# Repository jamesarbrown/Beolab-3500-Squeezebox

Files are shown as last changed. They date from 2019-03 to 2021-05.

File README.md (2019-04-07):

# Beolab-3500-Squeezebox

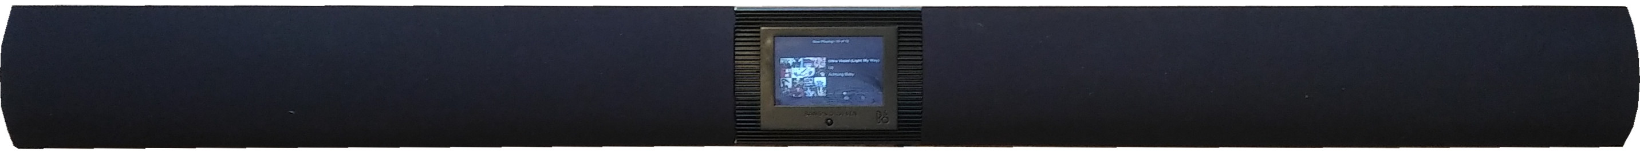
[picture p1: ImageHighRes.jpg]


This project is to convert and Bang and Olufsen Beolab 3500 into a Logitech Media Server / Slimdevices Squeezebox using Raspberry Pi and PiCorePlayer.

My first Squeezebox1 I bought from the US direct, long long before it was into the UK and since the range has been obsoleted by Logitech I wanted something a bit more than a streamer alone. There is a lot of B&O stuff in our family and it was a natural way to go, and most elegant equipment that has like all electronic stuff is soon out of date.

The project has a requirement for 3d printed parts and homemade PCBs

In no way is this project affiliated or representative of Bang and Olufsen, Logitech or Slimdevices. I have utilised the logos in my fascia designs, but if they need removing as companies sometimes do, I can do that, but don't feel this harms your brand identities. 

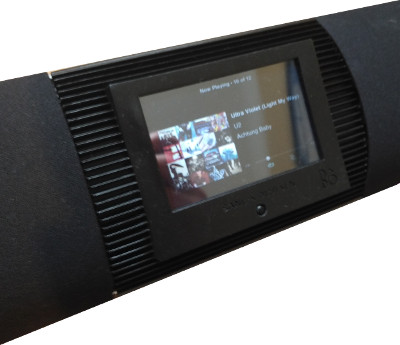
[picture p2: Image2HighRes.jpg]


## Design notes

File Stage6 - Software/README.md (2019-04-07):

## Installing and Setting Up

At the time of writing this is based on PiCorePlayer 4.1. I wont go into high details here just overview of tasks.

### Tasks

Once into PiCorePlayer web front end perform the following tasks

* Resize FS to whole SD Card
* Enable FFMPEG Libraries
* Setup HDMI detailed below
* Install jivelite via pCP web page
* Install Lirc as detailed below (this is important to do so we can set the jivelite resolution!)
* Set Skin to 640 x 480, this must match the hdmi_cvt settings (so the touch resolution matches the skin)
* Backup your settings on the pcp webpage

### Extensions to Enable
* nano

### Setup HDMI (KeDEI HDMI Screen 3.5")

In Rasberry config.txt File, (to edit ssh to PiCorePlayer, type m1, c1 and then ls to get to the file) edit as follows

At the end of the file add the HDMI info between the custom lines
```
#Custom Configuration Area, for config settings that are not managed by pCP.
#pCP will retain these settings during insitu-update
#---Begin-Custom-(Do not alter Begin or End Tags)-----
#For the display
hdmi_force_hotplug=1
hdmi_group=2
hdmi_mode=1
hdmi_mode=87
hdmi_cvt 640 480 60 6 0 0 0
hdmi_drive=2
display_rotate=2

#For the touchscreen
dtoverlay=ads7846,cs=0,penirq=25,speed=10000,penirq_pull=2,keep_vref_on=1,xohms=150
#---End-Custom----------------------------------------
```

### Install LIRC

Install lirc via the pCP web page
Once rebooted go back into the Lirc page and set the GPIO to 18 (if using the connections in this project)

### Setup the touchscreen

Run the commands and follow screen. Note that you need to disable jivelite autostart if you skipped ahead and have installed that. Once done you can reenable the autostart.

___ It must match the screen resolution set in config.txt and the skin resolution ___

___ It must be run as root... running as sudo does not change root settings which pcp runs on ___

```
root@piCorePlayer:/mnt/mmcblk0p1$ cat /proc/bus/input/devices
I: Bus=0000 Vendor=0000 Product=0000 Version=0000
N: Name="ADS7846 Touchscreen"
P: Phys=spi0.0/input0
S: Sysfs=/devices/platform/soc/3f204000.spi/spi_master/spi0/spi0.0/input/input0
U: Uniq=
H: Handlers=mouse0 event0
B: PROP=0
B: EV=b
B: KEY=400 0 0 0 0 0 0 0 0 0 0
B: ABS=1000003

root@piCorePlayer:~$ TSLIB_TSDEVICE=/dev/input/event0 /usr/local/bin/ts_calibrate
xres = 640, yres = 480
Took 1 samples...
Top left : X =  358 Y = 3832
Took 4 samples...
Top right : X =  215 Y =  201
Took 7 samples...
Bot right : X = 3652 Y =  228
Took 6 samples...
Bot left : X = 3659 Y = 3939
Took 3 samples...
Center : X = 2048 Y = 2000
658.083069 0.003269 -0.168910
-25.536713 0.136478 -0.002727
Calibration constants: 43128132 214 -11069 -1673574 8944 -178 65536
```
Can then be tested via
```
root@piCorePlayer:~$ TSLIB_TSDEVICE=/dev/input/event0 /usr/local/bin/ts_test
```

And don't forget
```
filetool.sh -b
```

### Edit pcpstartup
/home/tc/www/cgi-bin/pcp_startup.sh
Comment out the FT5406 and force the event no
```
eventno=$( cat /proc/bus/input/devices | awk '/FT5406 memory based driver/{....
```
to
```
eventno=$( cat /proc/bus/input/devices | awk '/ADS7846 Touchscreen/{....
```
And then don't forget to filetool.sh -b

This sets the following environment flags

```
export JIVE_NOCURSOR=1
export TSLIB_TSDEVICE=/dev/input/$eventno
export SDL_MOUSEDRV=TSLIB
export SDL_MOUSEDEV=$TSLIB_TSDEVICE

```
### Scripts for PON PLIM, PMUTE etc
In this folder is a file called beo3500.sh.

Please copy this into /home/tc and then in user commands in the pCP webinterface add

```
sleep 5; /home/tc/beo3500.sh > /dev/null
```

The script will auto power on and off the amplifiers based on the player status.

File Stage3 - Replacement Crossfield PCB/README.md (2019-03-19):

## Stage 3 - Replacement Crossfield and Ribbon Cables

### Ribbon Cable Replacements

| Function | New Length | Ways | Socket on Beolab | RS PN Plugs |
| --- |:---:| :---:| :---: | ---: |
| Right Hand Side Amp | 380mm | 8 | P2 | 680-5148 |
| Left Hand Side Amp  | 520mm | 8 | P2 | 680-5148 |
| Right Hand Side Amp | 370mm | 12 | P18 | 680-4933 |
| TX "Left" | 520mm | 4 | P21 | 341-7349 |

Note 10 way ribbon P17 to P5 is removed and not replaced. On ribbon cable bought a length of 14 way and cut down for other sections

In later stages the right hand side and left hand amps will be swapped around to create space for the crossfield PCB

## Crossfield PCB Folders

I made the PCB utilising laser printer thermal transfer method. 

In the following folders please finds

### PDFs

Crossfield PCB.pdf - The PCB to Print

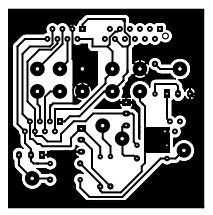
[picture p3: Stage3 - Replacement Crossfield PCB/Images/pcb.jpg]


Crossfield Schematic.pdf - The Schematic of the above PCB

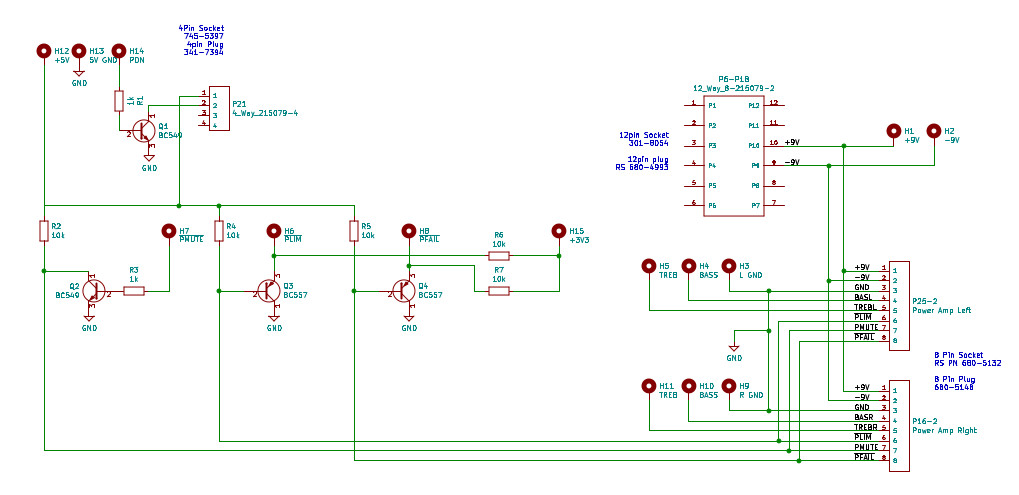
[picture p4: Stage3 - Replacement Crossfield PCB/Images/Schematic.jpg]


### Crossfield PCB Replacement (KiCAD Project)
The original KiCAD Design files, including the TE connectivity plugs and so on

#### Notes 
I had difficulty in nailing down the PFAIL and PLIM functions, so copied the way they originally were immplemented into the B&O microcomputer. Then used a BC549 to separate the circuit from the Raspberry. My suspicion was I could pull down the 3v3 directly, but went for this way to achieve some security.

### 3d from Kicad of PCB

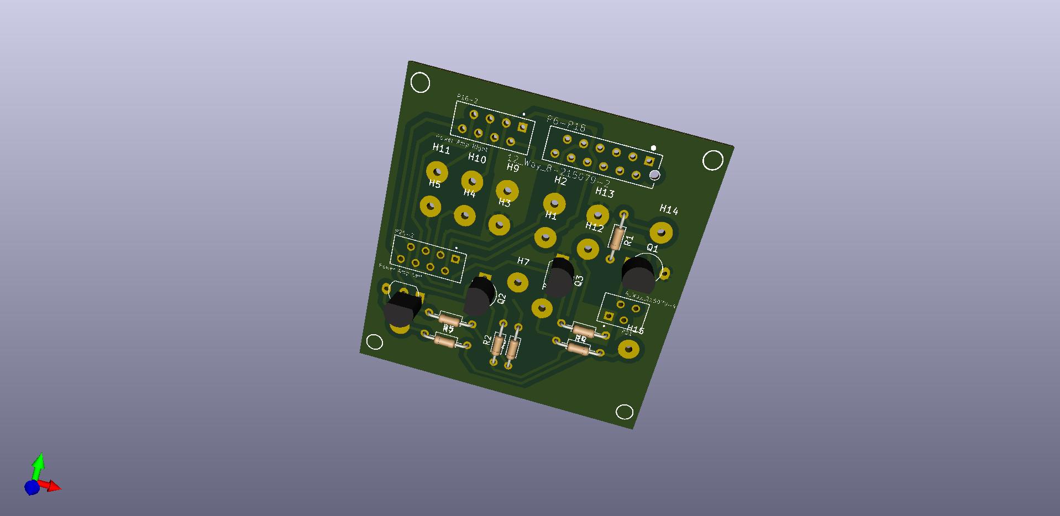
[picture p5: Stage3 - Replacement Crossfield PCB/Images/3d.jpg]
3d


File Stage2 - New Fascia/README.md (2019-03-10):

## Stage 2 - New Fascia

The fascia holds the Raspberry pi, the screen, the KM Tech cross overs.

### 3d Renders

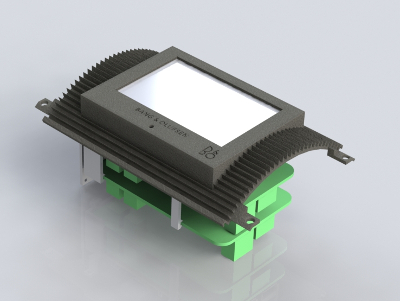
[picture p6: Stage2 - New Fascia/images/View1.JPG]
Render1


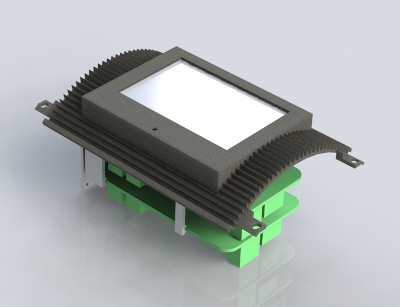
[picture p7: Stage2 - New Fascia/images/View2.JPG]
Render2


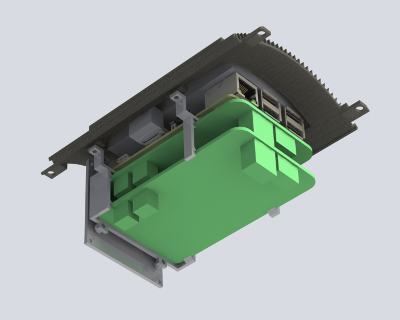
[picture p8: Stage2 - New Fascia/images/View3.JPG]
Render3


### IR Receiver

The IR receiver I bonded to the back of the fascia. This one is a TSOP4838

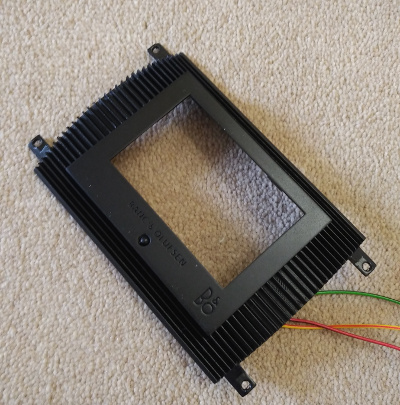
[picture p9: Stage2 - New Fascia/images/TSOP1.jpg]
TSOP1


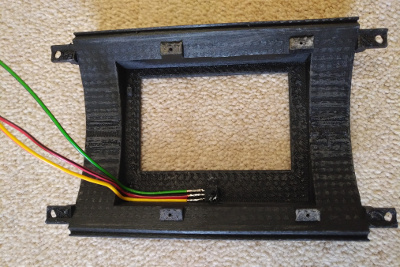
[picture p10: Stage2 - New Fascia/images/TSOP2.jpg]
TSOP2


#### Misc Notes

I found the Kedei screen was at a 1mm angle, so there is a 1mm thick printable wasaher as a spacer included in this project

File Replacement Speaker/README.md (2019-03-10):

## Replacing the B&O Original Speakers with Alternative
This section was implmented as during my investigations one of my speakers was damaged and the coil scratching.

The bracket detailed in here is to accept a Visatron FRS8 speaker 8Ohm 30watt. The B&O speaker is 3.25" which is very odd and forms part of the plastics. This speaker is 3".

The original Solidworks file is here should you want to utilise an alternative speaker

### Original Speaker with Foam Removed, before I realised it was far more damaged
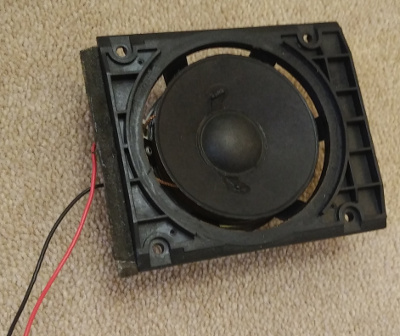
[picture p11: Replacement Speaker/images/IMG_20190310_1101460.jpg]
Speaker Original


### Replacement Speaker and Bracket
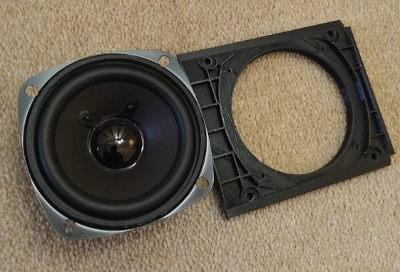
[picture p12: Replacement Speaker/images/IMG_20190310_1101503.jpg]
Speaker New 1

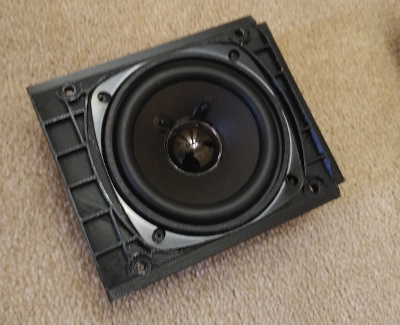
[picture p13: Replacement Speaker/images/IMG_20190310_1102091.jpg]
Speaker New 2


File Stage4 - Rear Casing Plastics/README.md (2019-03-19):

## Rear Casing Plastics

Due to removal of the aluminium diecast parts to make space for this project, I needed to make a new rear casing.

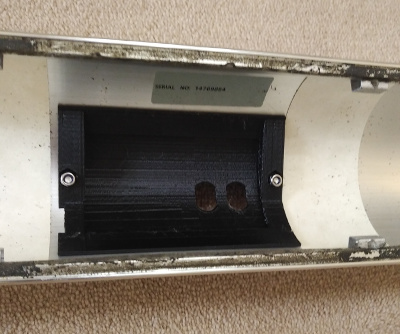
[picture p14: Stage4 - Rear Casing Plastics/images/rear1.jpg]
rear1


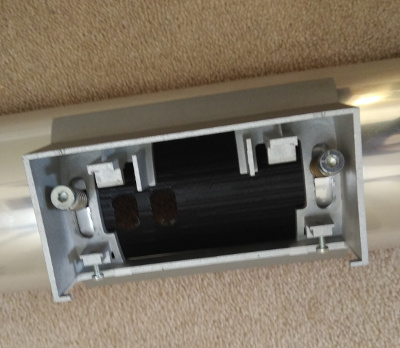
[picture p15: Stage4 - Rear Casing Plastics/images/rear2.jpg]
rear2


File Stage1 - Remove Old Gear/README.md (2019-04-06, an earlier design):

## Stage 1 - Removed the old parts

First I removed the old parts including
* Micro computer
* Alu Brackets
* Lifted out the amps and removed the ribbons

### Here is a Photo just as I began to attach new ribbons (Detailed in Stage 2)

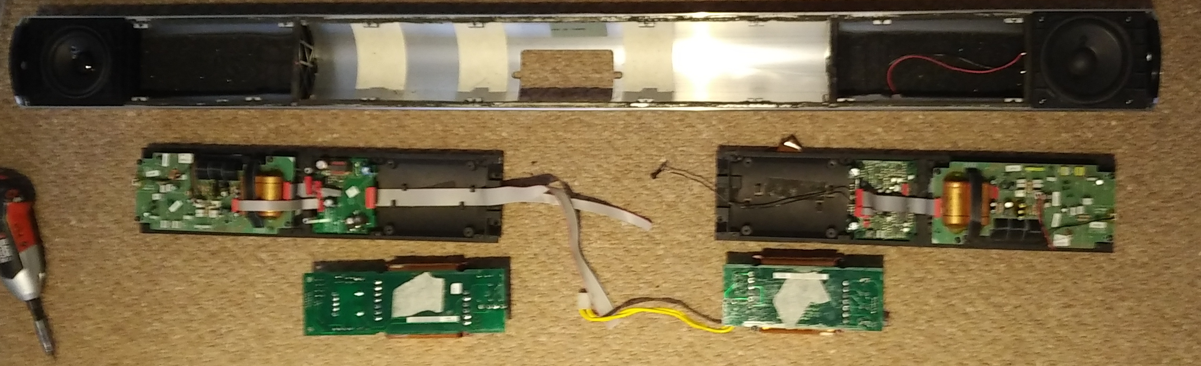
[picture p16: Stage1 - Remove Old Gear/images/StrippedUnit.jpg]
Stripped Down BeoLab3500


_Note the Switchmode PSU was later removed and also the TX modified. See wiring overview. Also the Rh and LH amps will be swapped for space reasons

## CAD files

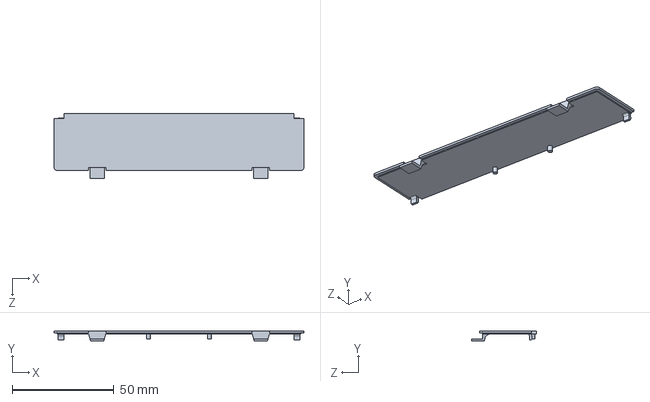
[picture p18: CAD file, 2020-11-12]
3500ReplacementCover/Replacement Cover.SLDPRT
123.0 x 5.00 x 32.0 mm

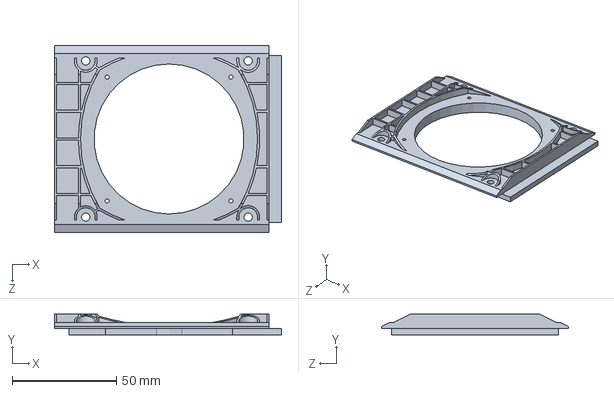
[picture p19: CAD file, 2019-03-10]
Replacement Speaker/Speaker Bracket.SLDPRT
109.0 x 10.0 x 90.0 mm

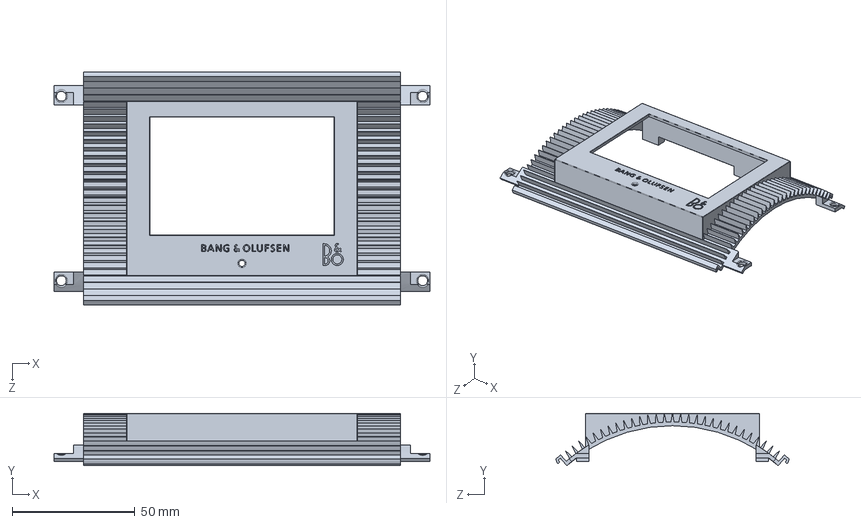
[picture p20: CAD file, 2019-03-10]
Stage2 - New Fascia/Solidworks Files/New Front.SLDPRT
153.0 x 21.3 x 95.0 mm

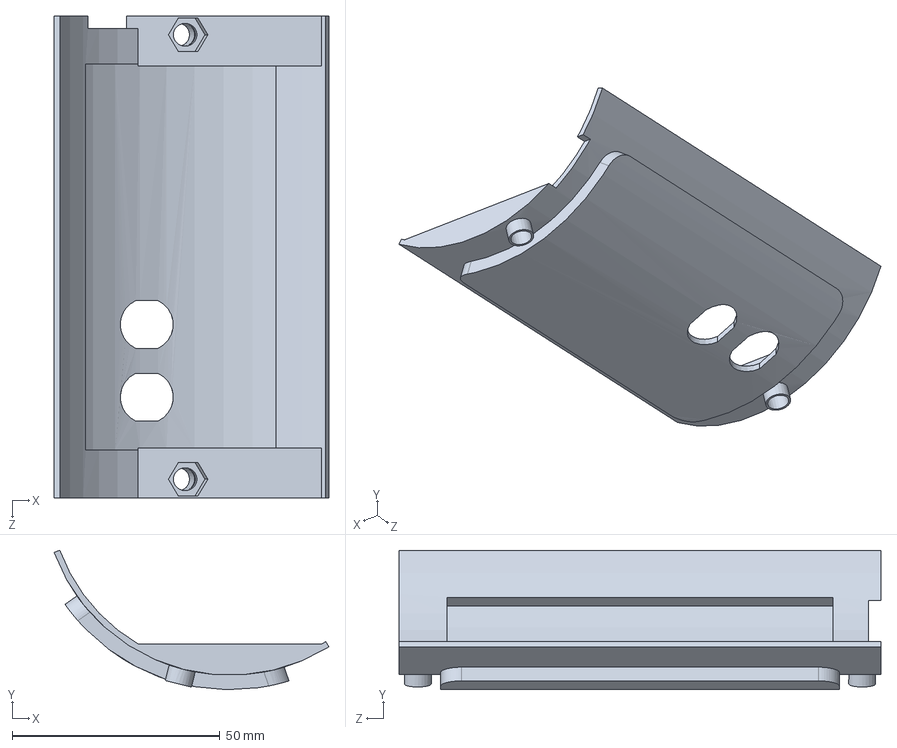
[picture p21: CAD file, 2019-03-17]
Stage4 - Rear Casing Plastics/3d Files/RearCasing.SLDPRT
66.2 x 33.6 x 116.0 mm

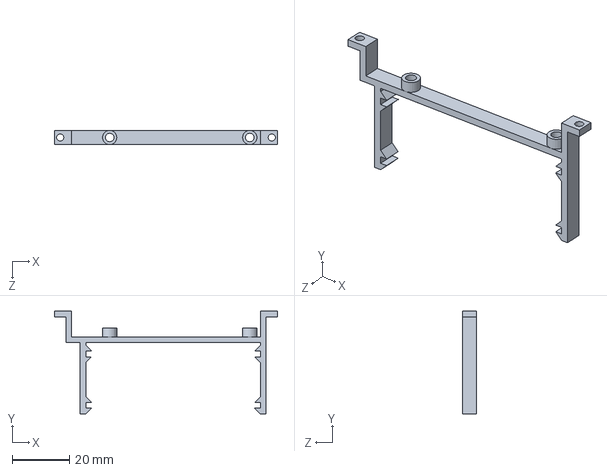
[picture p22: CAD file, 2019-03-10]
Stage2 - New Fascia/Solidworks Files/Bracket Fixing.SLDPRT
78.0 x 36.0 x 5.00 mm

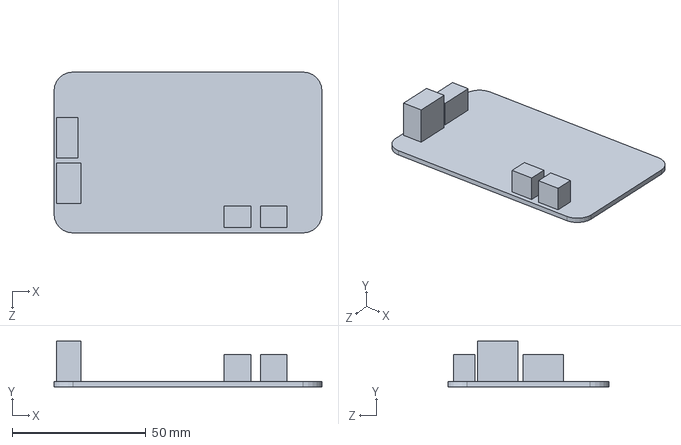
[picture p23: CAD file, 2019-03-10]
Stage2 - New Fascia/Solidworks Files/KMTech Active Filter.SLDPRT
100.0 x 17.0 x 60.0 mm

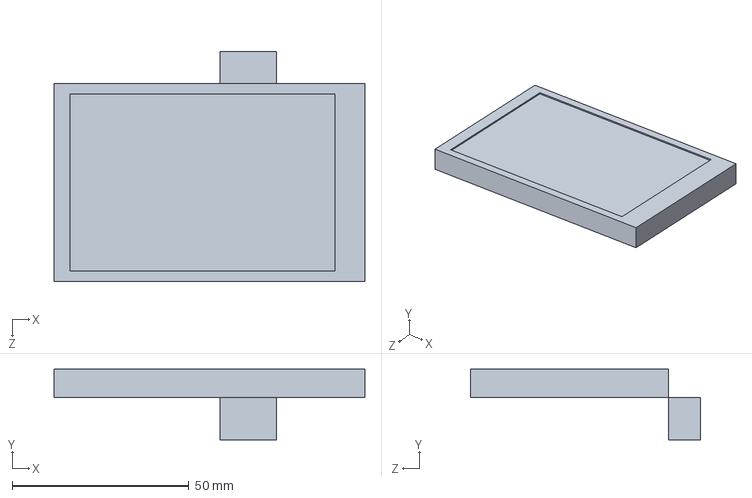
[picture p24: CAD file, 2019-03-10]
Stage2 - New Fascia/Solidworks Files/Kedei Display.SLDPRT
88.0 x 20.0 x 65.0 mm

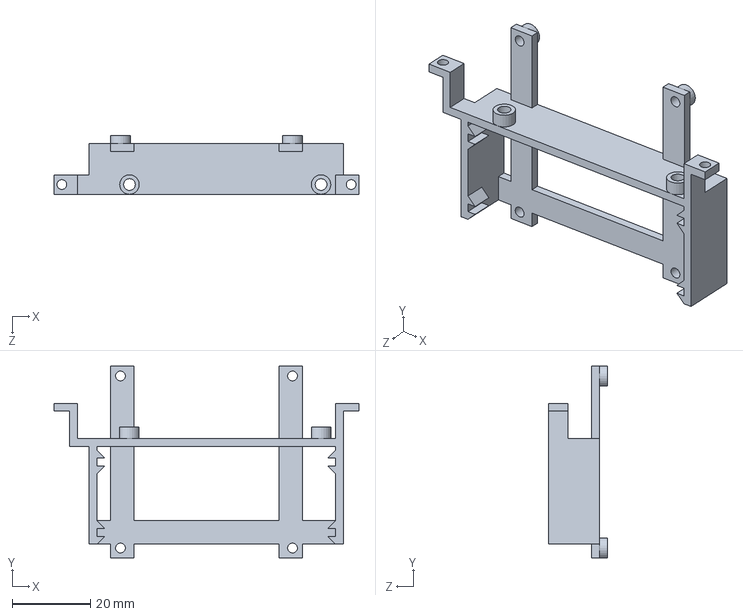
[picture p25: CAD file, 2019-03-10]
Stage2 - New Fascia/Solidworks Files/Bracket Fixing B.SLDPRT
78.0 x 49.0 x 15.0 mm

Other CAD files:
3500ReplacementCover/Replacement Cover.3MF
Replacement Speaker/Speaker Bracket.STL
Stage2 - New Fascia/STL Files/Bracket Fixing B.STL
Stage2 - New Fascia/STL Files/Bracket Fixing.STL
Stage2 - New Fascia/STL Files/New Front.STL
Stage4 - Rear Casing Plastics/3d Files/RearCasing.3MF

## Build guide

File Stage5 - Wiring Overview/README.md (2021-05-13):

## Wiring Overview

### Left Hand Side Amp Prep
The switchmode PSU onboard the Beolab is controlled via a LM3578 Buck convertor. It creates the 5v @ 750mA. Initially it was intended to use this however the Pi turns to be a bit power hungry and official PSU pulls 2A

This is the PSU

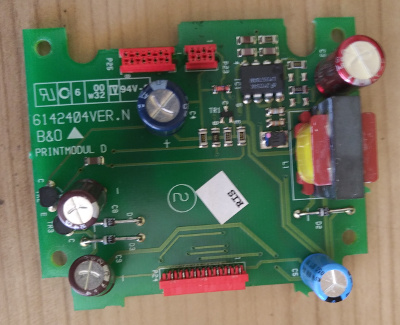
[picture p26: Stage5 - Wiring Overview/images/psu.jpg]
PSU


Then to create a bit more space remove the TX T1 and capacitor C1 from the left hand side TX.

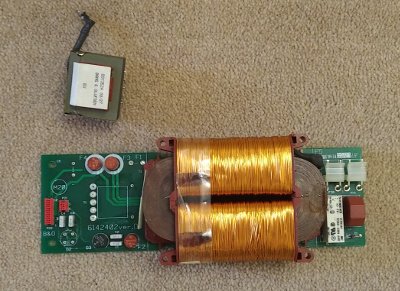
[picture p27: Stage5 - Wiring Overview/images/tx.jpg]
tx


After a second failed attempt with a Samsung PSU, a third failed attempt with a "cheap" 2A and audio noise, finally I bought a Raspberry PSU and but the case in two. Here is the PSU bonded in its final position.

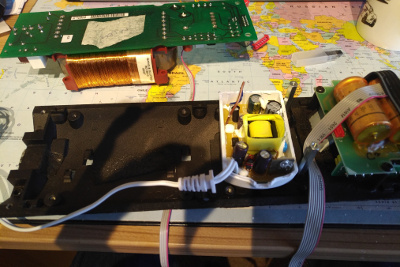
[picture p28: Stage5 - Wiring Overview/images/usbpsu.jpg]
usbpsu


Connect to the B&O pcb where Live and Neutral used to be for the Mini TX

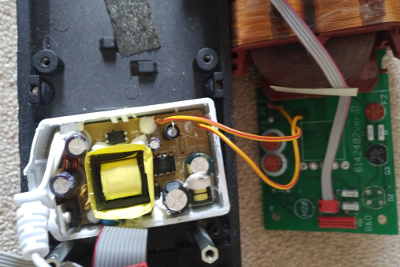
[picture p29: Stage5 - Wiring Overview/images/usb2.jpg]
usb2


I extracted the AC plug pins and soldered a longer flex onto it

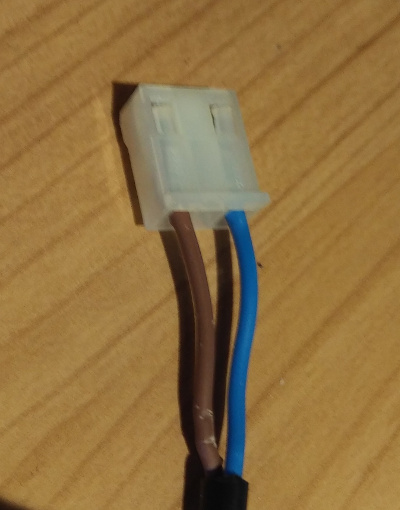
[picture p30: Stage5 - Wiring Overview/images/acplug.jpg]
acplug


Then finally fitted the Left hand system, but in the _RIGHT_ hand side, this is important as the display orientation, the gear around it, means this assembly with is stuck out PCB must go on the right. On the left it will not fit!

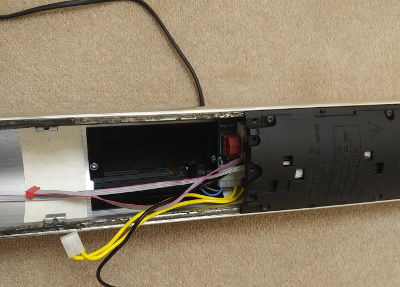
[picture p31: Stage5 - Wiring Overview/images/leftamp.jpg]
leftamp


Note the ferrite core I attached to the DC cable RS PN 123-2479

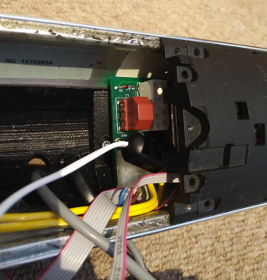
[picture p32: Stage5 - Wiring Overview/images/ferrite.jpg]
ferrite


### Main Wiring Diagram

The main wiring diagram is included in this folder in ODG and PDF format

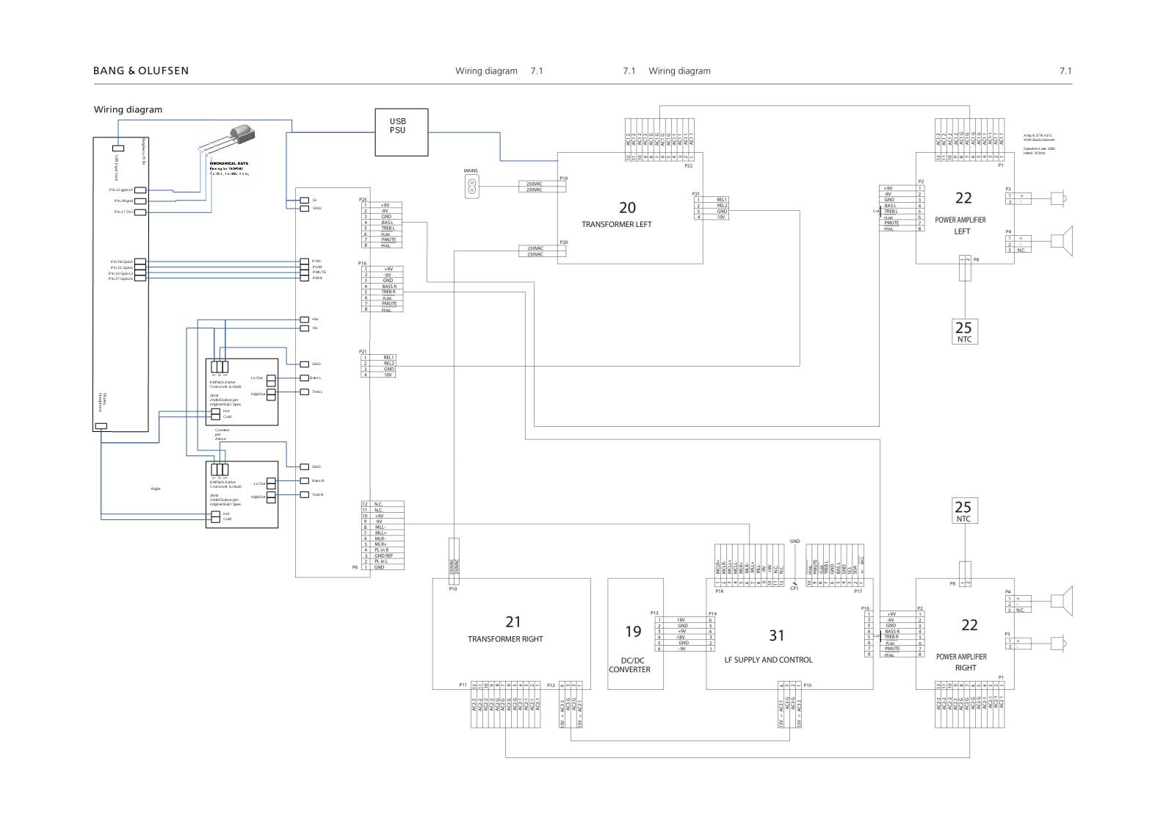
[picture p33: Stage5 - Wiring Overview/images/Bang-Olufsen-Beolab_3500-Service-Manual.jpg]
Wiring


### KM Tech Crossovers

In line with the B&O service manual the crossover needs to be 3kHz and on this project KM Tech units were utilisied. It would have been more ideal to have everything on one board and tighter spacing, so maybe a future implementation.

[Link to Buying on Ebay](https://www.ebay.co.uk/itm/122126121492?hash=item1c6f48ba14:g:sCAAAOSw-kdX07iY)

### Other Notes

After a failed attempt with a bad connection and bad audio from the primary 3.5mm Audio jack, i decided to solder the audio leads directly onto the audio jack for the Kedei display. On the body there is sufficient exposed metal to solder too without having to demount or worry about PCB work.

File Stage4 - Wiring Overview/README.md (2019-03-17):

##Wiring Overview

###Removal of B&O Switchmode PSU

The switchmode PSU onboard the Beolab is controlled via a LM3578 Buck convertor. It creates the 5v @ 750mA. Initially it was intended to use this however on startup the voltage was found to collapse

This is the PSU
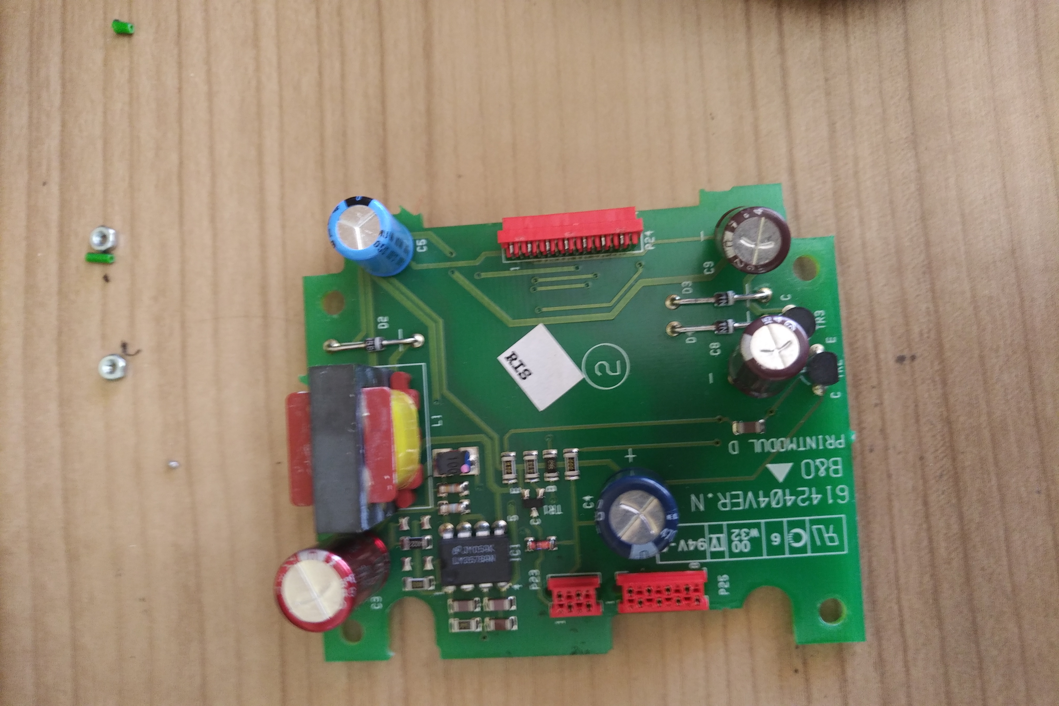
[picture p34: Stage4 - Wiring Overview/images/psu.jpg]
PSU


The Kedei and Raspberry use about 750mA Combined, there was a view to shorting the R4+R5 resistors out on the switchmode, but in diagnosis I damaged the LM3578. So decided to dispose and replace with a typical USB PSU designed for the job

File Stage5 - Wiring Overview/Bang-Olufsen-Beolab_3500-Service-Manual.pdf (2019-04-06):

# USB PSU

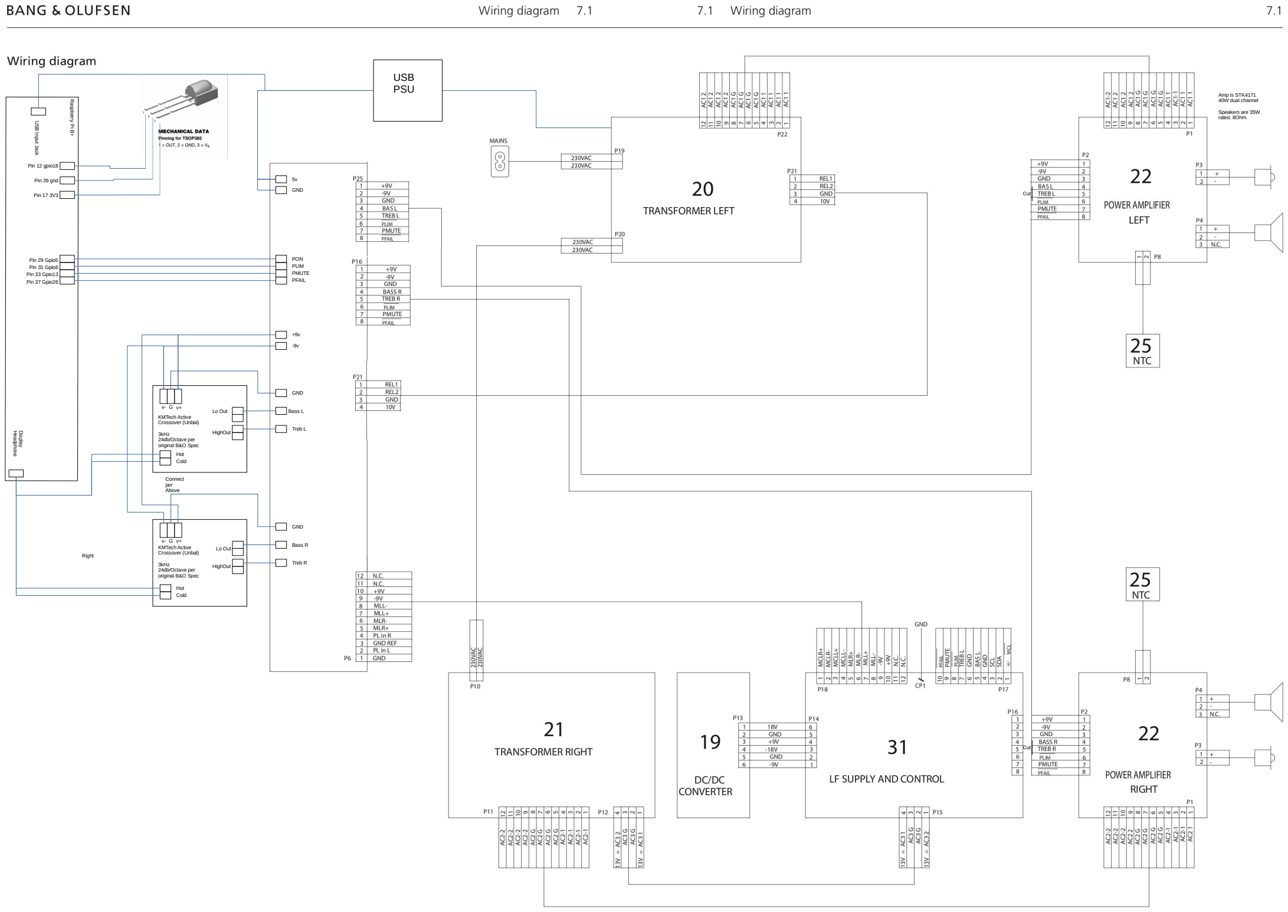
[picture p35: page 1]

Cut

HighOut

Cut

v-

G v+
KMTech Active
Crossover (Unbal)

3kHz
24db/Octave per
original B&O Spec

Amp is STK4171
40W dual channel

Speakers are 35W
rated. 8Ohm.

Raspberry Pi B+

Display

Headphone

Cold

Hot

USB Input Jack

HighOut

Lo Out

v-

G v+
KMTech Active
Crossover (Unbal)

3kHz
24db/Octave per
original B&O Spec

Cold

Hot

Right

Connect
per
Above

Pin 29 Gpio5

Pin 17 3V3

Pin 39 gnd

Pin 12 gpio18

Lo Out

Bass R

Treb R

Bass L

Treb L

GND

GND

+9v

-9v

PON
Pin 31 Gpio6 | PLIM
Pin 33 Gpio13 | PMUTE
Pin 37 Gpio26 | PFAIL

5v

GND

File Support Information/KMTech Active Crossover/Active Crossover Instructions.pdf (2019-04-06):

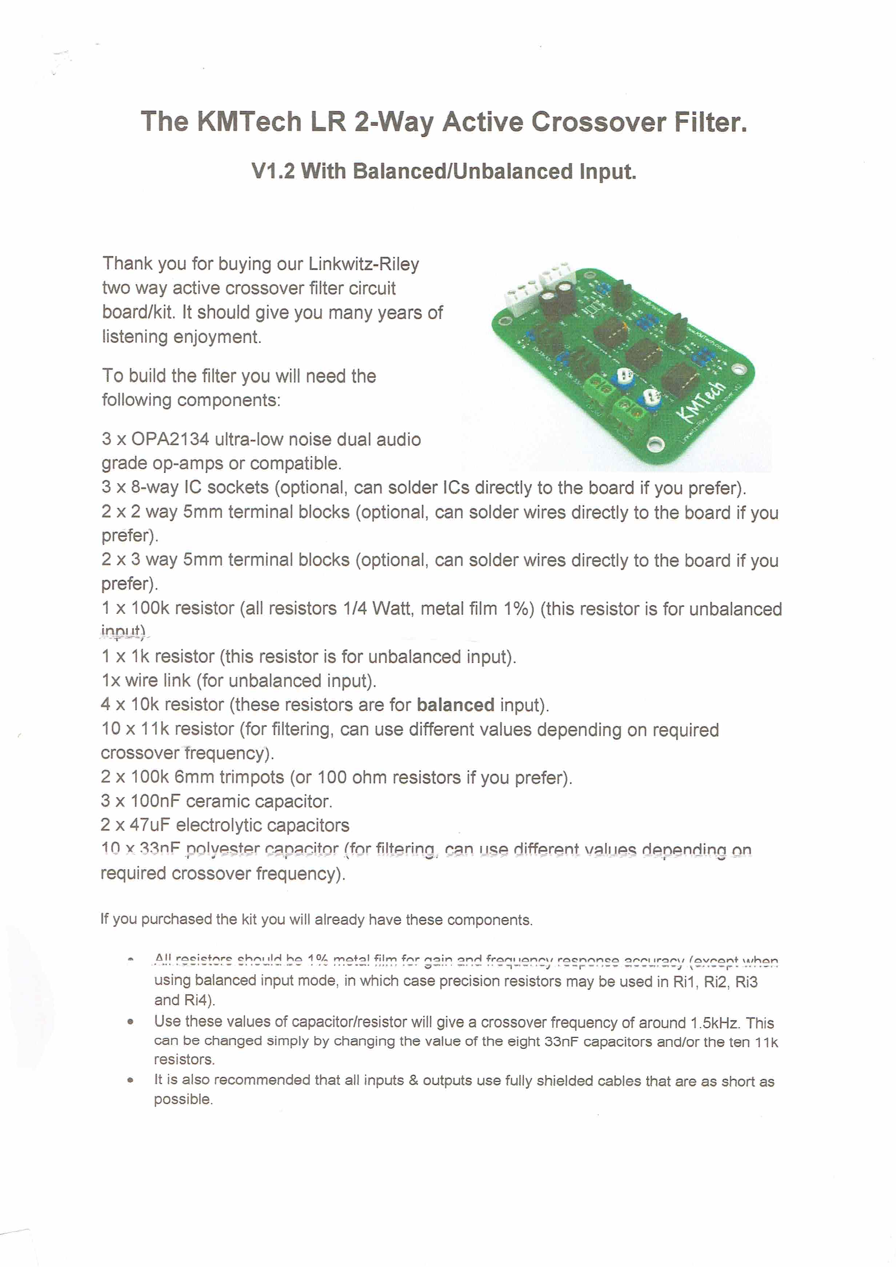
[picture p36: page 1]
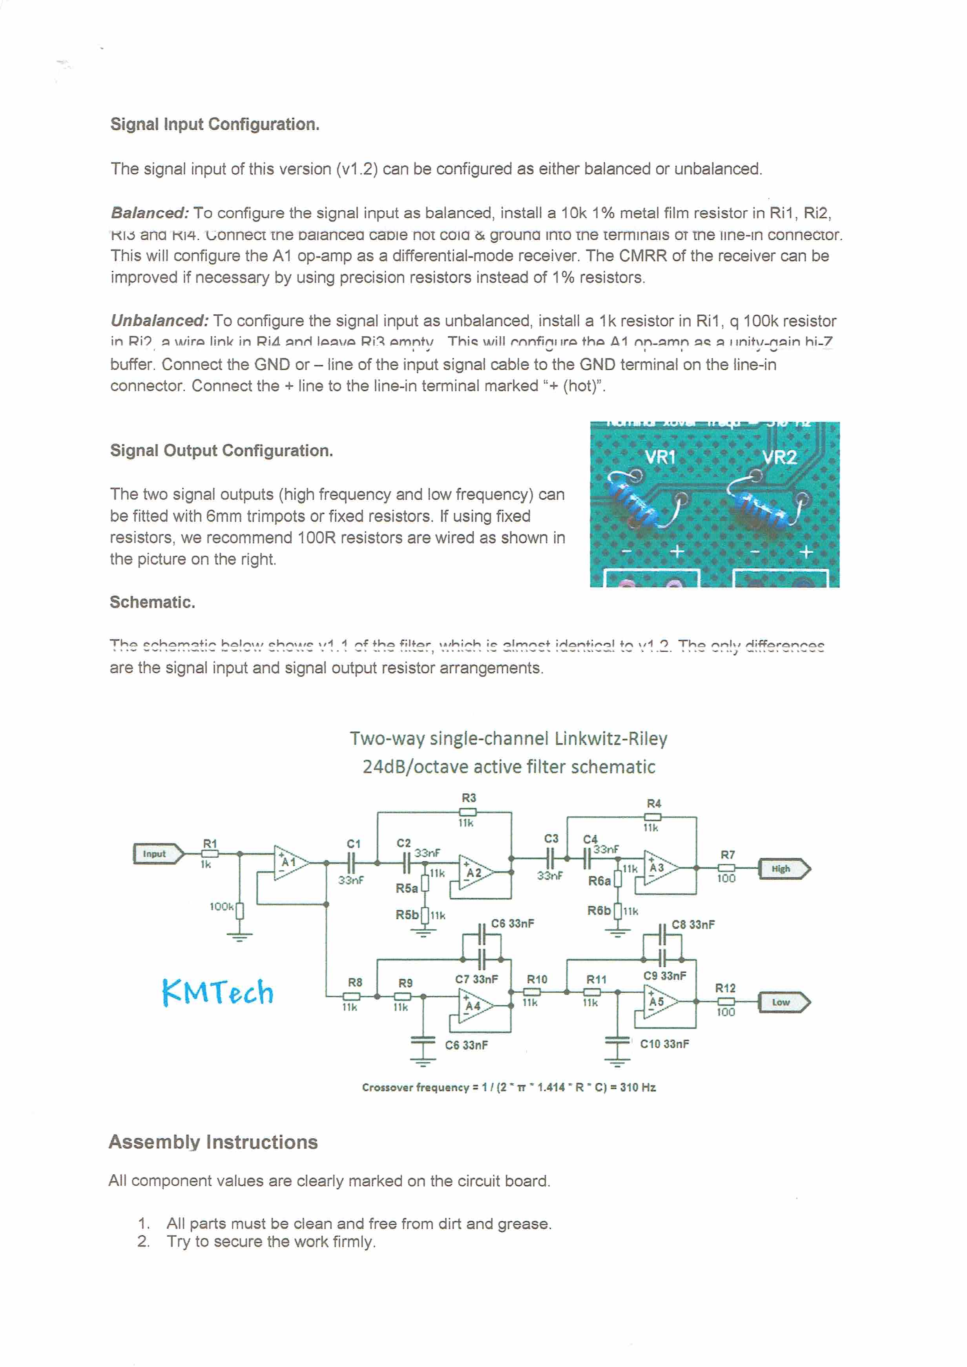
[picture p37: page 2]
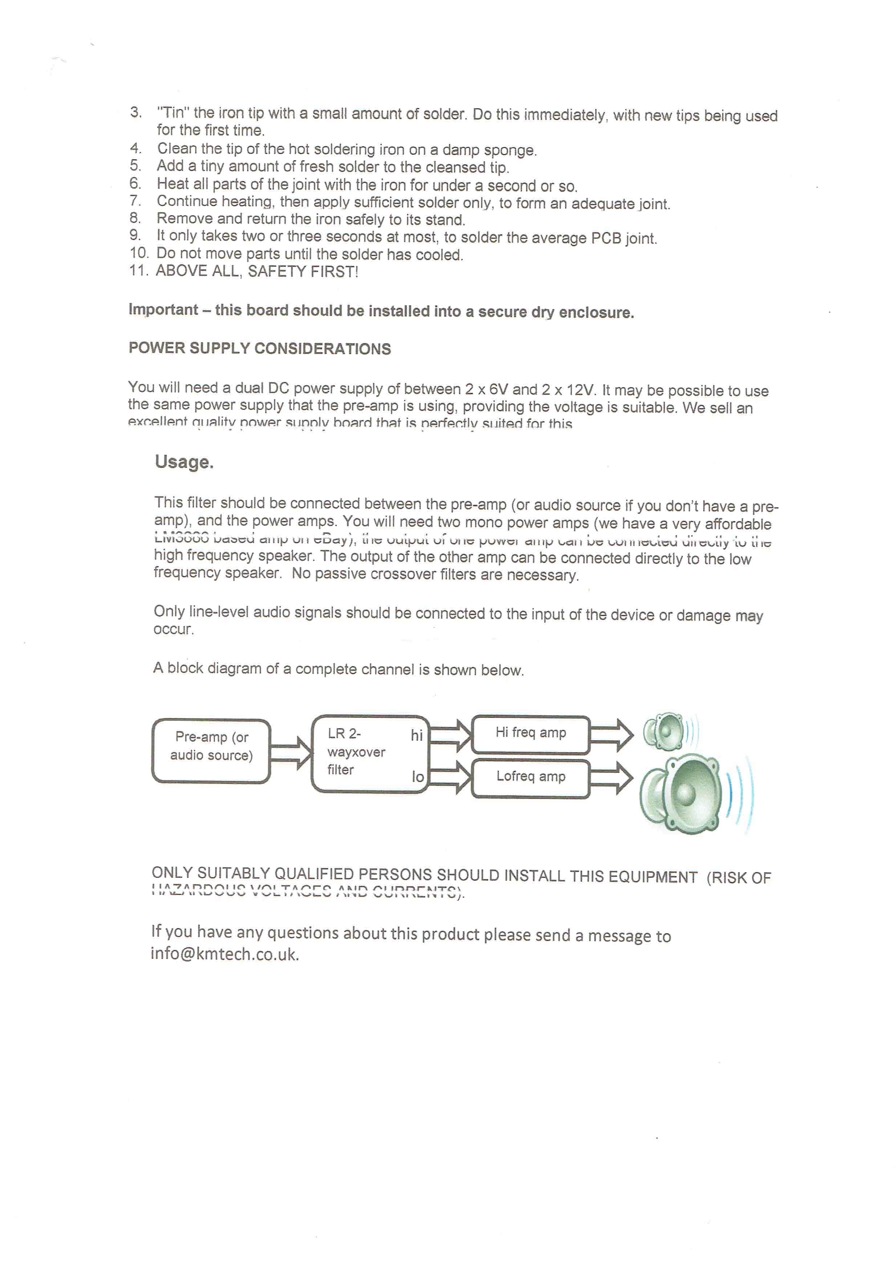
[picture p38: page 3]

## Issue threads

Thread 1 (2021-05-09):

KMTech Crossover  out of production

CzarofAK, 2021-05-09:
Hello James, thanks a lot for your effort you put into that manual!
I have no ordered five of your panels from jlcpcb as I cant produce pcb yet.
sadly the kmtech crossover is not in production anymore. what crossover would you suggest as a replacement?
Best regards Gabriel

jamesarbrown, 2021-05-09:
#response_container_BBPPID{font-family: initial; font-size:initial; color: initial;} Hi,Hope its use, im going to build another soon, so i hope the documentation is all good!Not sure. If kmtech dont make i wonder if they would sell the diagrams/pcb layoutsYes i would also use jlcpcb these daysI did just look on ebay and is the attached not it?One of my disappointment was some background noise from the pi on very low volume and when you stopped the squeeze box until the pi scripts caught the stop and turned off the b+o amp. If you want to make any improvement consider that area. But its all very very tight in that casingJames                                                                                                                                             Sent via BlackBerry Hub+ Inbox for Android                                                                                                                                                                           From: ***@***.***Sent: 9 May 2021 13:34To: ***@***.***Reply to: ***@***.***Cc: ***@***.***Subject: [jamesarbrown/Beolab-3500-Squeezebox] KMTech Crossover  out of production (#1)
Hello James, thanks a lot for your effort you put into that manual!
I have no ordered five of your panels from jlcpcb as I cant produce pcb yet.
sadly the kmtech crossover is not in production anymore. what crossover would you suggest as a replacement?
Best regards Gabriel

—You are receiving this because you are subscribed to this thread.Reply to this email directly, view it on GitHub, or unsubscribe.

jamesarbrown, 2021-05-12:
#response_container_BBPPID{font-family: initial; font-size:initial; color: initial;}  https://www.ebay.co.uk/itm/122126121492I just google kmtech on ebay i can see the bare board and a completed board£8stg and £28stg respectively                                                                                                                                             Sent via BlackBerry Hub+ Inbox for Android                                                                                                                                                                           From: ***@***.***Sent: 11 May 2021 22:15To: ***@***.***Reply to: ***@***.***Cc: ***@***.***; ***@***.***Subject: Re: [jamesarbrown/Beolab-3500-Squeezebox] KMTech Crossover  out of production (#1)
Sadly you attachement did not make it in GitHub. do you have a Link?
just got my first BEOLAB here on my table. lets see if I can disassemble it.

—You are receiving this because you commented.Reply to this email directly, view it on GitHub, or unsubscribe.

CzarofAK, 2021-05-13:
Unbalanced / 310Hz Crossover, correct?

jamesarbrown, 2021-05-13:
Humm that sounds like an error. In support folder in the b+o service i am reading a crossover of 3000hz. So i would have thought i went to nearest kmtech  version

I can also not recall on balanced or unbalanced, i would need to work through that again to discover

CzarofAK, 2021-05-13:
Well, the guy from the Ebay shop asked me, how he should configure it.
As we are using Phone jack or Cinch, it should be unbalanced. balanced are used for XLR and such.

CzarofAK, 2021-05-13:
Yes, you are right. it seems like the crossover frequency is 3000. seems also to be legit, with the size of the speakers.
Going to order it like that:
Unbalanced, 3000Hz Crossover

jamesarbrown, 2021-05-13:
Yes I have finally found this confirming 3Khz crossover

[Wiring Diagram in This Repository](
https://raw.githubusercontent.com/jamesarbrown/Beolab-3500-Squeezebox/master/Stage5%20-%20Wiring%20Overview/images/Bang-Olufsen-Beolab_3500-Service-Manual.jpg
)

Containing
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

Closed 2021-05-13.

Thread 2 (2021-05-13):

Sound quality of the Headphone jack

CzarofAK, 2021-05-13:
I thought about the Raspberry Pi Audio output quality.
For my speaker i am going to derive a bit from your configuration.
There are two different possible ways for me to realize a better Sound output quality:
1. Keep the Display but use a USB audio card such as "Sandberg USB to Sound Link" or "Creative Sound Blaster Play!3"
2. Leave the Display away, and use instead a Hifiberry DAC+ with stereo cinch output

jamesarbrown, 2021-05-13:
Hi @CzarofAK maybe fork this project and we can pull back anything that is worth doing?

The casing is exceptionally tight, as ideally the KMTechs would have been better all on one board. Maybe in future I could make the crossover, but there is an audiophile skill there to set them that is probably beyond me.

The 3.5mm jack was only of minor annoyance, so I am betting that a USB Creative Sound Blaster (and that its on a cable allowing perhaps to put it in a gap between the Pi or KM Techs) may work out.

Closed 2021-05-20.

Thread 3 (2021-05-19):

Bill of Material for the "Replacement Crossfield PCB"

CzarofAK, 2021-05-19:
I have now ordered (mouser.ch) all the parts required for the "Replacement Crossfield PCB":
1x TE Connectivity, Headers & Wire Housings Headers & Wire Housings MOW 04P 28 AWG, 7-215083-4
2x TE Connectivity, Headers & Wire Housings Headers & Wire Housings MOW 08P 28 AWG, 215083-8
1x TE Connectivity, Headers & Wire Housings MOW 18P 28 AWG, 8-215083-8
2x ON Semiconductor / Fairchild, Bipolar Transistors - BJT Bipolar Transistors - BJT PNP -45V -100mA HFE/220, C557ATA
2x ON Semiconductor / Fairchild, Bipolar Transistors - BJT Bipolar Transistors - BJT NPN 30V 100mA HFE/450, BC549BTA
2x Vishay / BC Components, Metal Film Resistors - Through Hole Metal Film Resistors - Through Hole 1/2watt 1Kohms 5%, SFR16S0001001JA500
5x Vishay / BC Components, Metal Film Resistors - Through Hole Metal Film Resistors - Through Hole 1/2watt 10Kohms 5%,
SFR16S0001002JA500
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

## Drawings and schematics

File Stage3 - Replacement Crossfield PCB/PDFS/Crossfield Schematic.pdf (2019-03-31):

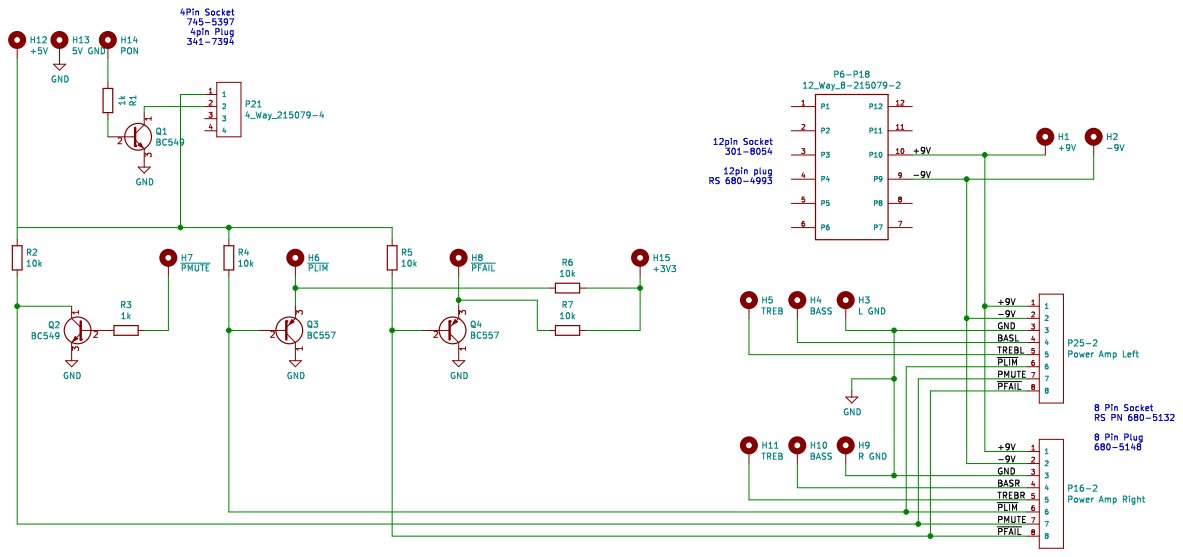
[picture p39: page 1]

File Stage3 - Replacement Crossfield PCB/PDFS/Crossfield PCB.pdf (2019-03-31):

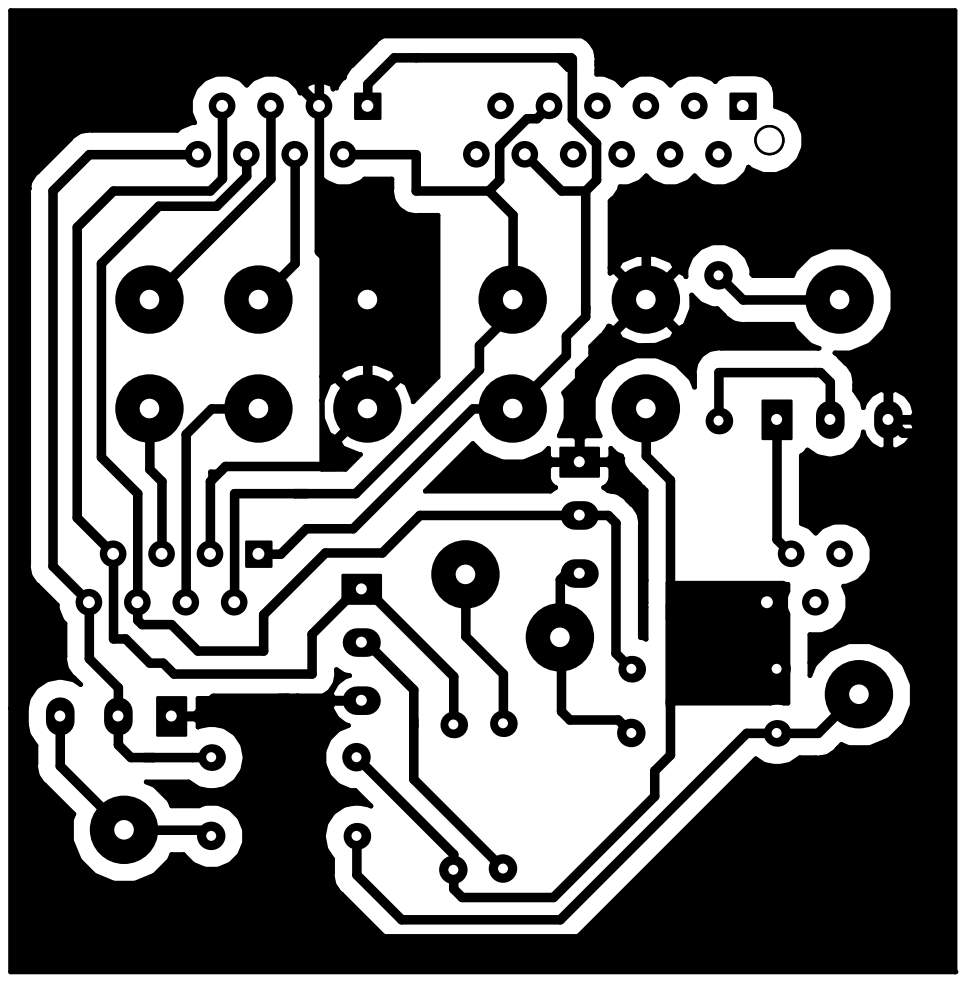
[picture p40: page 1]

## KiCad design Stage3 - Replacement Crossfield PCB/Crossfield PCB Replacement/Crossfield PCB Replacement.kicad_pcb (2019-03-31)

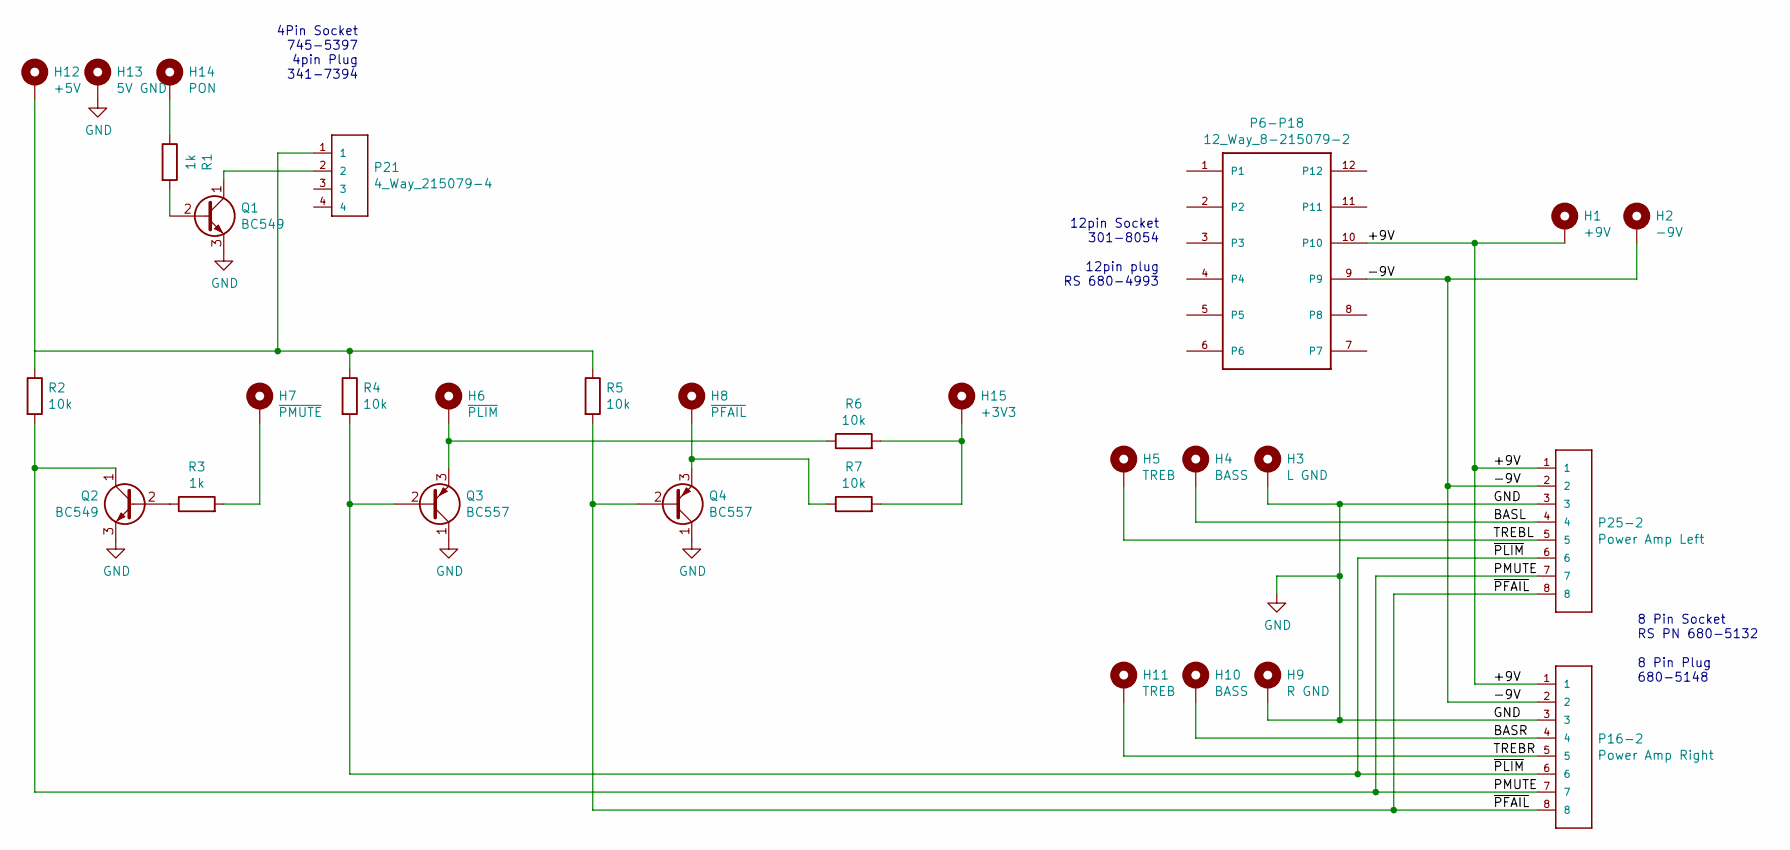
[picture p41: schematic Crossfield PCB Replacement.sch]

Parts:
H1: +9V; SolderWirePad_1x01_Drill1.2mm
H2: -9V; SolderWirePad_1x01_Drill1.2mm
H3: L GND; SolderWirePad_1x01_Drill1.2mm
H4, H10: BASS; SolderWirePad_1x01_Drill1.2mm
H5, H11: TREB; SolderWirePad_1x01_Drill1.2mm
H6: ~PLIM; SolderWirePad_1x01_Drill1.2mm
H7: ~PMUTE; SolderWirePad_1x01_Drill1.2mm
H8: ~PFAIL; SolderWirePad_1x01_Drill1.2mm
H9: R GND; SolderWirePad_1x01_Drill1.2mm
H12: +5V; SolderWirePad_1x01_Drill1.2mm
H13: 5V GND; SolderWirePad_1x01_Drill1.2mm
H14: PON; SolderWirePad_1x01_Drill1.2mm
H15: +3V3; SolderWirePad_1x01_Drill1.2mm
P6-P18: 12_Way_8-215079-2; TE_8-215079-2
P16-2: Power Amp Right; TE_215079-8
P21: 4_Way_215079-4; TE_215079-4
P25-2: Power Amp Left; TE_215079-8
Q1, Q2: BC549; TO-92_Inline
Q3, Q4: BC557; TO-92_Inline
R1, R3: 1k; R_Axial_DIN0204_L3.6mm_D1.6mm_P7.62mm_Horizontal
R2, R4, R5, R6, R7: 10k; R_Axial_DIN0204_L3.6mm_D1.6mm_P7.62mm_Horizontal

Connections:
/+9V: H1.1, P6-P18.10, P16-2.1, P25-2.1
/-9V: H2.1, P6-P18.9, P16-2.2, P25-2.2
/BASL: H4.1, P25-2.4
/BASR: H10.1, P16-2.4
/PMUTE: P16-2.7, P25-2.7, Q2.1 (C), R2.2
/TREBL: H5.1, P25-2.5
/TREBR: H11.1, P16-2.5
/~PFAIL: P16-2.8, P25-2.8, Q4.2 (B), R5.2
/~PLIM: P16-2.6, P25-2.6, Q3.2 (B), R4.2
GND: H3.1, H9.1, H13.1, P16-2.3, P25-2.3, Q1.3 (E), Q2.3 (E), Q3.1 (C), Q4.1 (C)
unnamed: H6.1, Q3.3 (E), R6.1
unnamed: H7.1, R3.2
unnamed: H8.1, Q4.3 (E), R7.1
unnamed: H12.1, P21.1, R2.1, R4.1, R5.1
unnamed: H14.1, R1.1
unnamed: H15.1, R6.2, R7.2
unnamed: P21.2, Q1.1 (C)
unnamed: Q1.2 (B), R1.2
unnamed: Q2.2 (B), R3.1

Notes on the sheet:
8 Pin Socket RS PN 680-5132 8 Pin Plug 680-5148
12pin Socket 301-8054 12pin plug RS 680-4993
4Pin Socket 745-5397 4pin Plug 341-7394

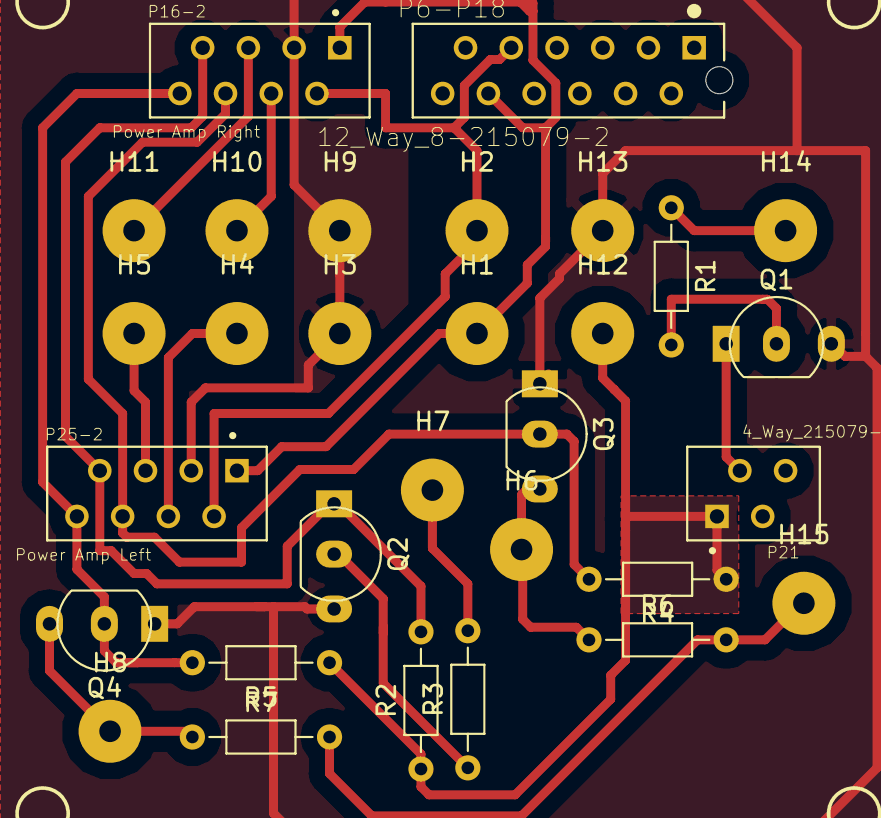
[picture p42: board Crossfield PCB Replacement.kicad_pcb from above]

Board: 2 copper layers, 30 parts (0 on the bottom side), 19 nets.

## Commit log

2019-03-10 Added replacement speaker info
    [Speaker Bracket.SLDPRT, Speaker Bracket.STL]
2019-03-10 Added flashforge printer files
2019-03-10 Added Solidworks Part and Assy files
    [Bracket Fixing B.SLDPRT, Bracket Fixing.SLDPRT, KMTech Active Filter.SLDPRT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]
2019-03-10 Added STL
    [Bracket Fixing B.STL, Bracket Fixing.STL, New Front.STL]
2019-03-11 Added PCB and Schematic
2019-03-11 Added KiCAD FIles
    [Crossfield PCB Replacement.kicad_pcb, Crossfield PCB Replacement.sch]
2019-03-17 Fixed mains cable position holes
    [RearCasing.3MF, RearCasing.SLDPRT]
2019-03-17 Flashforge printer files
2019-03-17 First Stage of PSU Conversion
2019-03-17 Added Flashforge printer files for speaker bracket
2019-03-17 Adjusted Cable holes to suit RS PN 817-8873
    [RearCasing.3MF, RearCasing.SLDPRT]
2019-03-17 New Printer Files for Rear Casing
2019-03-17 Fixed Pin No Ordering on 12 Way Connector
2019-03-18 Changed PCB now has USB PSU
    The B&O PSU failed to provide enough mA for the raspberry. Now the switchmode PSU has been removed and replaced with a standard USB brick.
    [Crossfield PCB Replacement.kicad_pcb, Crossfield PCB Replacement.sch]
2019-03-18 Amended the Ribbon Cables
    Removed the switchmode PSU at this stage
2019-03-18 Updated Crossfield Designs
    Removed the 14 way connector to the Switchmode PSU and added a 4 way connector direct to Left TX (operating the main power relay)
2019-03-19 Added images of USB power plug Stage
2019-03-23 Fixed Pinout on 12 pin connector
2019-03-23 Fixed PCB to suit new pin out
    [Crossfield PCB Replacement.kicad_pcb]
2019-03-23 PCB tweaks
    [Crossfield PCB Replacement.kicad_pcb]
2019-03-31 Updated PCB following tests on PMUTE
    [Crossfield PCB Replacement.kicad_pcb, Crossfield PCB Replacement.sch]
2019-03-31 Corrected PCB Image
2019-03-31 Widened legs on Transistors for easier working
    [Crossfield PCB Replacement.kicad_pcb]
2019-03-31 Fixed broken track
    [Crossfield PCB Replacement.kicad_pcb]
2019-04-06 Loaded correct schematic image
2019-04-06 Added Overview Wiring
2019-04-06 Updated Readme to include wiring diagram
2019-04-06 Auto Power Script
2020-11-12 Replacement Cover for Wall Bracket
    [Replacement Cover.3MF, Replacement Cover.SLDPRT]
